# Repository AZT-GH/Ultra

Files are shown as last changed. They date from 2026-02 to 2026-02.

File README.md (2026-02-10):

# AZUltra

Copyright © 2026 Adam Zembrzuski

Licensed under the TAPR Open Hardware License (www.tapr.org/OHL)
A full copy of the TAPR Open Hardware License is available in license.txt

<hr>

AZUltra is a periodic buzzer designed for space-constrained environments. Applications include warning alerts or sleep prevention. It is primarily a testbed for CH32V005 integration in my future projects.



View the project entirely in your browser on KiCanvas - https://kicanvas.org/?repo=https%3A%2F%2Fgithub.com%2FAZT-GH%2FUltra%2Ftree%2Fmain%2FGH_UPLOAD%2FAZUltra

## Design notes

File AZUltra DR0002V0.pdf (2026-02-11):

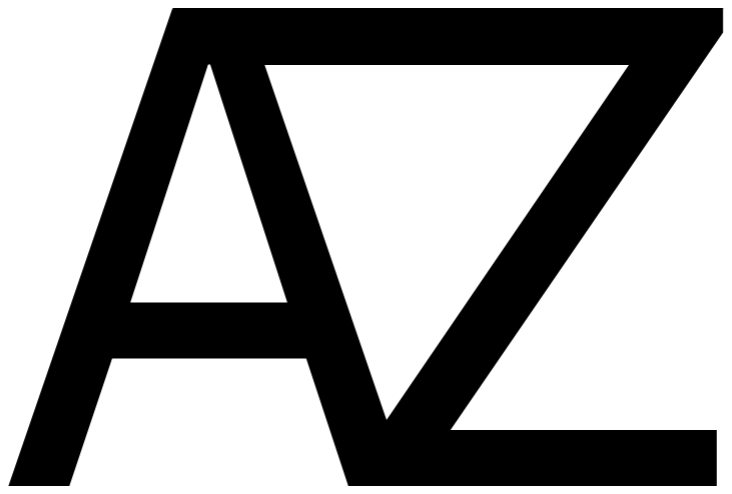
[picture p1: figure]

# AZUltra v0.01

## (Preliminary) Hardware Review 0002 - Version 1

AZUltra is a microcontroller-enabled buzzer with eight user-programmable modes.

### This document is intended as a review of the v0.01 hardware design. It will focus on the successes and failures of the first revision and detail a plan for future improvements if

another revision is deemed necessary. This is only a review of the hardware.

### Licensed under TAPR Open Hardware License

# CURRENTLY UNDER WRITING EXPECT CHANGES

# CONTENTS

CONTENTS | 1
CHANGELOG | 2
ABBREVIATIONS | 3
INTRODUCTION | 4
Context | 4
Design Intent | 4
Specification | 4
Schematic | 5
REVIEW | 6
Schematic | 6
Layout | 8
Improvements | 8
LICENSE | 9

# CHANGELOG

### V0 - Initial Commit - 10/02/26 - AZ V1 - Layout Review Complete - 11/02/26 - AZ

# ABBREVIATIONS

### uC - Microcontroller (GP) IO - (General Purpose) Input/Output PCB - Printed Circuit Board TVS - Transient Voltage Suppression EM - Electromagnetic ESD - Electrostatic Discharge PMOS - P Channel Metal Oxide Semiconductor Field Effect Transistor IC - Integrated Circuit

# INTRODUCTION

# Context

The idea for this project arose from the disappointment of a “cricket noise maker” I ordered

### from aliexpress. This product was comically quiet and when placed into the intended

environment - could be barely heard. Additionally, it used soldered batteries meaning it was difficult if not impossible to repair. It also was not user programmable due to a one time

### programmable microcontroller being used. This greatly inspired me to make my own

improved version.

# Design Intent

### To design a reliable, noticeable and repairable sound maker that would surpass options currently available on the market while maintaining a small form factor and low cost of

manufacture.

# Specification

## - At least 28 days of runtime on a single battery given one 200ms sound every

30 minutes.

## - Programming capability without expensive equipment

## - Versatile I/O allowing for connection to other equipment

## - Peak sound loudness of at least 80dB at 10cm

## - A maximum PCB size of 50mmx50mm

## - All small surface mount components on one side of the board (smaller than 15x15mm)

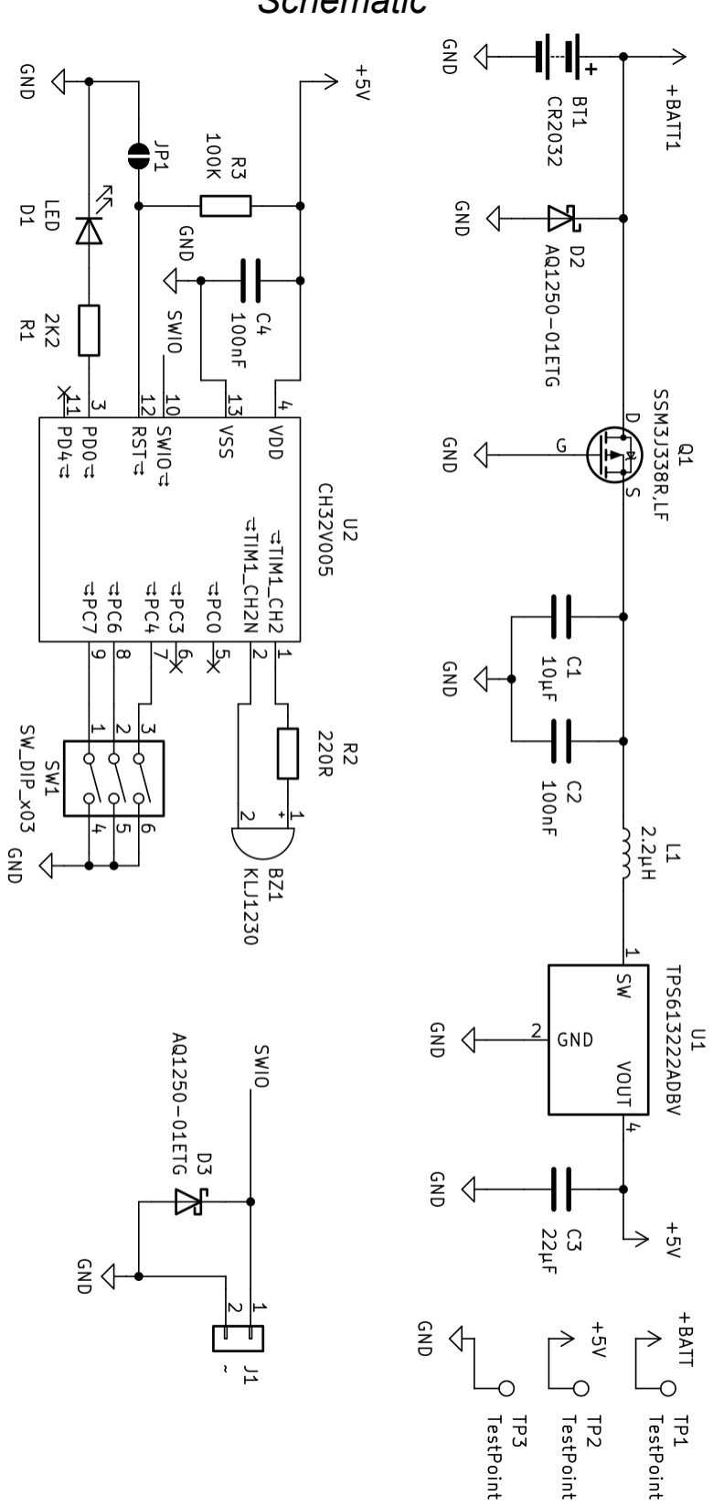
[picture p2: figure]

# Schematic

# REVIEW

# Schematic

The circuit (as seen in the previous page) is fairly simple. I chose the power source to be a

### CR2032 as they are fairly power dense, commonly available, do not require charging

circuitry and the holders come in a small footprint. An alternative would be the CR2450 as it has a much larger capacity, although they are more expensive, larger, and less common.

### The battery (and programming I/O) has a TVS diode to prevent damage from ESD events. I also implemented the Q1 PMOS for low loss reverse polarity protection. The specified part

should be substituted for a cheaper alternative if absolute cost-saving is a priority. I used the

### specified PMOS mostly due to the fact that I already had stock and that it had good

properties. Namely, low RDS_on and gate voltage.

This feeds into a boost converter boosting to 5V. The input caps are fairly standard and a low ESR power inductor with sufficient saturation current should be used for L1. In worst-case scenarios (low ambient temp and low quality, old cells) the converter would switch into PFM mode and leak noise through the uC timer peripheral into the piezo causing unwanted noise. For this reason a relatively large 22uf output cap was chosen in an attempt to mitigate the noise while keeping a relatively small package and cost. The boost converter was chosen as it had acceptable quiescent current and high efficiency . All with a very low bom count and

### implementation difficulty. A system voltage of 5V was chosen as it was near the maximum

acceptable operating voltage for the uC and enabled the piezo to stay at a consistent (and higher) loudness. There are also three test points to easily measure if the power is working.

Another reason for the development of this board was to test the CH32v00x platform of very cost efficient, feature-packed microcontrollers. The CH32v005 is one of the newer revisions and costs close to £0.25 per unit. They are available in a large range of packages, in this case I chose a very small QFN-12 unit. As for passives all it requires is a 100nF decoupling

### cap and a pull up on the reset pin. I chose a 100k pull up to balance noise immunity and power losses, I implemented the reset as an unlabelled jumper that can be bridged with a

screwdriver or similar. This is so that the device cannot be reset by third parties (without

### operating knowledge) in operation which is very useful for my use case. Ironically, this document removes that layer of security but if whoever finds this goes to the length of

reading this then they deserve to know how to reset the board.

### I dedicated one GPIO pin to an LED that can be used to verify programming and then can be

used by the user for whatever purposes they desire. I also used three GPIO pins for a 2 way

### dip switch to enable the user to switch between up to 8 modes on the fly. This could very

easily be switched out for a female connector to enable for the device to act on information

### from other devices (or expansion boards). As for connectors, the programming connector is a common JST-SH, Only two terminals are required due to the unique single wire

programming process (data and ground).

Finally, I chose a piezo buzzer due to their low current consumption and high loudness. The

### buzzer is connected push-pull to the complementary outputs of the advanced timer, timer1

on the ch32. This doubles the peak to peak potential difference compared to single end drive which greatly increases volume (~1.4x). I also added a series resistor to reduce ringing and noise (like aforementioned) while not drastically reducing volume.

# Layout

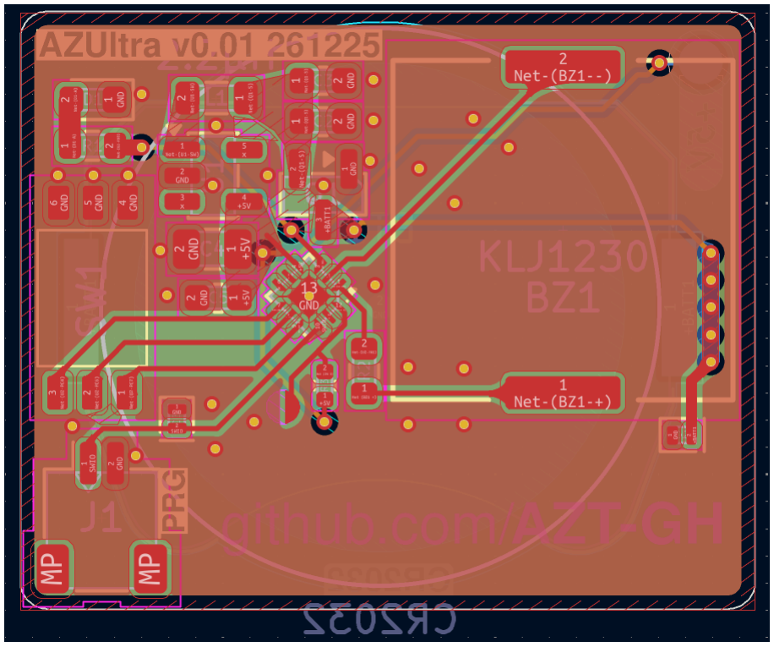
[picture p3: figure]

# Layout

I chose a four-layer PCB as it was the same cost from my supplier as a two-layer, and as I

### was concerned about the noise immunity of the PCB and thought that additional ground

planes would help. The stack is signal - ground - mixed - ground. The third layer consists of mostly a ground plane and some minimal power and signal routing.

### The PCB’s minimum size was constrained by the size of the CR2032 holder that I chose (Keystone 3034). I chose this holder as it was the easiest to solder by hand and also the smallest. A drawback was that the battery is not very securely secured and that there is

potential for soldermask on vias on the battery contact to be scraped, potentially causing shorts.

After defining the PCB edge, I roughly placed each component to ease routing later. Importantly, the passives that are a part of the DCDC switching loop are very close to the IC

### to reduce the loop area and EM emissions. They also all had ground vias placed near

ground pins to reduce the current loop and hence EM emissions. I also used copper fills for power connections to reduce their resistance thereby reducing power loss by ohmic losses.

The uC was placed centrally on the board to allow easy connection to all sides of the board.

### Similarly, the uC was rotated by 45 degrees to increase the ease of routing and enable larger separation between traces for noise immunity. Namely, the 3 dip switch needed 3 traces connected to the uC which were all spaced as much as possible to improve signal

integrity. Finally (as for functional considerations), I placed the programming connector near the edge of the PCB to allow for easy connections.

Considering aesthetical factors, I put an easily legible board label at the top, including name,

### version and date in knockout silkscreen. Similarly I labelled the programming header with

“PRG”. Also on the front side of the PCB, I removed the solder mask to expose my github on

### the ENIG/HASL. (github.com/AZT-GH) On the other side of the PCB I placed and labelled

the 5V test point and put silkscreen for the battery type on the battery entry.

# Improvements

### For some reason unknown to me I forgot to change the inner power traces to pours, in the next revision I would use pours to reduce the resistance as mentioned above. I would also

change the JST-SH connector for a more easily crimpable connector as after a lot of effort I was unable to crimp connectors and had to purchase precrimped wire.

In the next revision I would also replace the 3 position dip switch with a connector so that other boards could communicate to the AZUltra to enable environment based buzzing.

# LICENSE

### The TAPR Open Hardware License Version 1.0 (May 25, 2007) Copyright 2007 TAPR - http://www.tapr.org/OHL

PREAMBLE

Open Hardware is a thing - a physical artifact, either electrical or mechanical - whose design information is available to, and usable by, the public in a way that allows anyone to make, modify, distribute, and use that thing. In this preface, design information is called "documentation" and things created from it are called "products."

The TAPR Open Hardware License ("OHL") agreement provides a legal framework for Open Hardware projects. It may be used for any kind of product, be it a hammer or a computer motherboard, and is TAPR's contribution to the community; anyone may use the OHL for their Open Hardware project.

Like the GNU General Public License, the OHL is designed to guarantee your freedom to share and to create. It forbids anyone who receives rights under the OHL to deny any other licensee those same rights to copy, modify, and distribute documentation, and to make, use and distribute products based on that documentation.

Unlike the GPL, the OHL is not primarily a copyright license. While copyright protects documentation from unauthorized copying, modification, and distribution, it has little to do with your right to make, distribute,
or use a product based on that documentation. For better or worse, patents play a significant role in those activities. Although it does not prohibit
anyone from patenting inventions embodied in an Open Hardware design, and of course cannot prevent a third party from enforcing their patent rights,
those who benefit from an OHL design may not bring lawsuits claiming that design infringes their patents or other intellectual property.

The OHL addresses unique issues involved in the creation of tangible, physical things, but does not cover software, firmware, or code loaded into programmable devices. A copyright-oriented license such as the GPL better suits these creations.

How can you use the OHL, or a design based upon it? While the terms and conditions below take precedence over this preamble, here is a summary:

* You may modify the documentation and make products based upon it.

* You may use products for any legal purpose without limitation.

* You may distribute unmodified documentation, but you must include the complete package as you received it.

* You may distribute products you make to third parties, if you either include the documentation on which the product is based, or make it available without charge for at least three years to anyone who requests it.

* You may distribute modified documentation or products based on it, if you:
* License your modifications under the OHL.
* Include those modifications, following the requirements stated below.
* Attempt to send the modified documentation by email to any of the developers who have provided their email address. This is a good faith obligation - if the email fails, you need do nothing more
and may go on with your distribution.

* If you create a design that you want to license under the OHL, you should:
* Include this document in a file named LICENSE (with the appropriate extension) that is included in the documentation package.
* If the file format allows, include a notice like "Licensed under
the TAPR Open Hardware License (www.tapr.org/OHL)" in each documentation file. While not required, you should also include this notice on printed circuit board artwork and the product itself; if space is limited the notice can be shortened or abbreviated.
* Include a copyright notice in each file and on printed circuit board artwork.
* If you wish to be notified of modifications that others may make, include your email address in a file named "CONTRIB.TXT" or something similar.

* Any time the OHL requires you to make documentation available to others, you must include all the materials you received from the upstream licensors. In addition, if you have modified the documentation:
* You must identify the modifications in a text file (preferably
named "CHANGES.TXT") that you include with the documentation. That file must also include a statement like "These modifications are licensed under the TAPR Open Hardware License."
* You must include any new files you created, including any manufacturing files (such as Gerber files) you create in the course of making products.
* You must include both "before" and "after" versions of all files you modified.
* You may include files in proprietary formats, but you must also include open format versions (such as Gerber, ASCII, Postscript, or PDF) if your tools can create them.

TERMS AND CONDITIONS

1. Introduction
1.1 This Agreement governs how you may use, copy, modify, and distribute Documentation, and how you may make, have made, and distribute Products based on that Documentation. As used in this Agreement, to "distribute" Documentation means to directly or indirectly make copies available to a third party, and to "distribute" Products means to directly or indirectly give, loan, sell or otherwise transfer
them to a third party.

1.2 "Documentation" includes:
(a) schematic diagrams;

(b) circuit or circuit board layouts, including Gerber and other
data files used for manufacture;
(c) mechanical drawings, including CAD, CAM, and other data files used for manufacture;
(d) flow charts and descriptive text; and
(e) other explanatory material.
Documentation may be in any tangible or intangible form of expression, including but not limited to computer files in open or proprietary formats and representations on paper, film, or other media.

1.3 "Products" include:
(a) circuit boards, mechanical assemblies, and other physical parts and components;
(b) assembled or partially assembled units (including components and subassemblies); and
(c) parts and components combined into kits intended for assembly by others;
which are based in whole or in part on the Documentation.

1.4 This Agreement applies to any Documentation which contains a notice stating it is subject to the TAPR Open Hardware License, and to all Products based in whole or in part on that Documentation. If Documentation is distributed in an archive (such as a "zip" file) which includes this document, all files in that archive are subject to this Agreement unless they are specifically excluded. Each person who contributes content to the Documentation is referred to in this Agreement as a "Licensor."

1.5 By (a) using, copying, modifying, or distributing the
Documentation, or (b) making or having Products made or distributing them, you accept this Agreement, agree to comply with its terms, and become a "Licensee." Any activity inconsistent with this Agreement will automatically terminate your rights under it (including the immunities from suit granted in Section 2), but the rights of others who have received Documentation, or have obtained Products, directly or indirectly from you will not be affected so long as they fully comply
with it themselves.

1.6 This Agreement does not apply to software, firmware, or code loaded into programmable devices which may be used in conjunction with Documentation or Products. Such software is subject to the license terms established by its copyright holder(s).

2. Patents
2.1 Each Licensor grants you, every other Licensee, and every possessor or user of Products a perpetual, worldwide, and royalty-free immunity from suit under any patent, patent application, or other intellectual property right which he or she controls, to the extent necessary to make, have made, possess, use, and distribute Products. This immunity does not extend to infringement arising from modifications subsequently made by others.

2.2 If you make or have Products made, or distribute Documentation that you have modified, you grant every Licensor, every other Licensee, and every possessor or user of Products a perpetual, worldwide, and royalty-free immunity from suit under any patent, patent application, or other intellectual property right which you control, to the extent necessary to make, have made, possess, use, and distribute Products.

This immunity does not extend to infringement arising from modifications subsequently made by others.

2.3 To avoid doubt, providing Documentation to a third party for the sole purpose of having that party make Products on your behalf is not considered "distribution,"\" and a third party's act of making Products solely on your behalf does not cause that party to grant the immunity described in the preceding paragraph.

2.4 These grants of immunity are a material part of this Agreement, and form a portion of the consideration given by each party to the other. If any court judgment or legal agreement prevents you from granting the immunity required by this Section, your rights under this Agreement will terminate and you may no longer use, copy, modify or distribute the Documentation, or make, have made, or distribute Products.

3. Modifications
You may modify the Documentation, and those modifications will become part of the Documentation. They are subject to this Agreement, as are Products based in whole or in part on them. If you distribute the modified Documentation, or Products based in whole or in part upon it, you must email the modified Documentation in a form compliant with Section 4 to each Licensor who has provided an email address with the Documentation. Attempting to send the email completes your obligations under this Section and you need take no further action if any address fails.
4. Distributing Documentation
4.1 You may distribute unmodified copies of the Documentation in its entirety in any medium, provided that you retain all copyright and other notices (including references to this Agreement) included by each

Licensor, and include an unaltered copy of this Agreement.
4.2 You may distribute modified copies of the Documentation if you comply with all the requirements of the preceding paragraph and:
(a) include a prominent notice in an ASCII or other open format file identifying those elements of the Documentation that you changed, and stating that the modifications are licensed under the terms of this Agreement;
(b) include all new documentation files that you create, as well as both the original and modified versions of each file you change (files may be in your development tool's native file format,
but if reasonably possible, you must also include open format, such as Gerber, ASCII, Postscript, or PDF, versions);
(c) do not change the terms of this Agreement with respect to subsequent licensees; and
(d) if you make or have Products made, include in the Documentation all elements reasonably required to permit others to make Products, including Gerber, CAD/CAM and other files used for manufacture.
5. Making Products
5.1 You may use the Documentation to make or have Products made, provided that each Product retains any notices included by the Licensor (including, but not limited to, copyright notices on circuit boards).

5.2 You may distribute Products you make or have made, provided that you include with each unit a copy of the Documentation in a form consistent with Section 4. Alternatively, you may include either (i) an offer valid for at least three years to provide that Documentation, at
no charge other than the reasonable cost of media and postage, to any person who requests it; or (ii) a URL where that Documentation may be downloaded, available for at least three years after you last distribute the Product.
6. NEW LICENSE VERSIONS
TAPR may publish updated versions of the OHL which retain the same general provisions as the present version, but differ in detail to
address new problems or concerns, and carry a distinguishing version number. If the Documentation specifies a version number which applies to it and "any later version", you may choose either that version or any later version published by TAPR. If the Documentation does not specify a version number, you may choose any version ever published by TAPR. TAPR owns the copyright to the OHL, but grants permission to any person to copy, distribute, and use it in unmodified form.
7. WARRANTY AND LIABILITY LIMITATIONS
7.1 THE DOCUMENTATION IS PROVIDED ON AN"AS-IS" BASIS WITHOUT WARRANTY OF ANY KIND, TO THE EXTENT PERMITTED BY APPLICABLE LAW. ALL WARRANTIES, EXPRESS OR IMPLIED, INCLUDING BUT NOT LIMITED TO ANY WARRANTIES OF MERCHANTABILITY, FITNESS FOR A PARTICULAR PURPOSE, AND TITLE, ARE HEREBY EXPRESSLY DISCLAIMED.

7.2 IN NO EVENT UNLESS REQUIRED BY APPLICABLE LAW WILL ANY LICENSOR
BE LIABLE TO YOU OR ANY THIRD PARTY FOR ANY DIRECT, INDIRECT,
INCIDENTAL, CONSEQUENTIAL, PUNITIVE, OR EXEMPLARY DAMAGES ARISING OUT OF THE USE OF, OR INABILITY TO USE, THE DOCUMENTATION OR PRODUCTS, INCLUDING BUT NOT LIMITED TO CLAIMS OF INTELLECTUAL PROPERTY INFRINGEMENT OR LOSS OF DATA, EVEN IF THAT PARTY HAS BEEN ADVISED OF THE POSSIBILITY OF SUCH DAMAGES.

7.3 You agree that the foregoing limitations are reasonable due to
the non-financial nature of the transaction represented by this
Agreement, and acknowledge that were it not for these limitations, the Licensor(s) would not be willing to make the Documentation available to you.

7.4 You agree to defend, indemnify, and hold each Licensor harmless from any claim brought by a third party alleging any defect in the design, manufacture, or operation of any Product which you make, have made, or distribute pursuant to this Agreement.

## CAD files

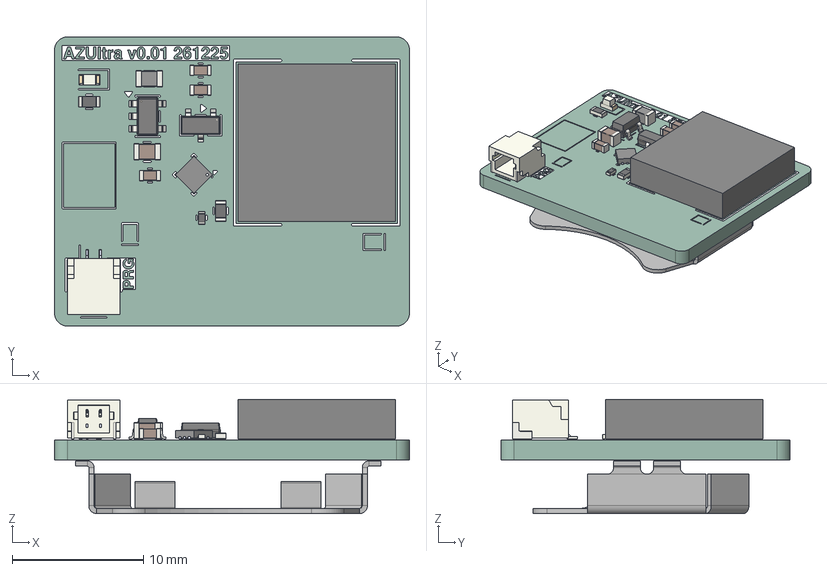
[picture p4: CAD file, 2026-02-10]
GH_UPLOAD/AZUltra/AZUltra.step
27.0 x 22.0 x 8.68 mm
R_0402_1005Metric
LED_0603_1608Metric
L_0805_2012Metric
SOT-23
KLJ1230
SOT-23-5
C_0603_1608Metric x 3
C_0805_2012Metric
Body_Solid1
Body001_Solid1
Array_Solid1 x 3
Array001_Solid2 x 2
Body002_Solid1
Array002_Solid1 x 3
Array003_Solid2 x 2
Body003_Solid1
Body004_Solid1
JST_SH_SM02B-SRSS-TB_1x02-1MP_P1.00mm_Horizontal
SM02B-SRSS-TB-LF
R_0603_1608Metric x 2
BatteryHolder_Keystone_3034_1x20mm
AZUltra_silkscreen x 2
AZUltra_PCB

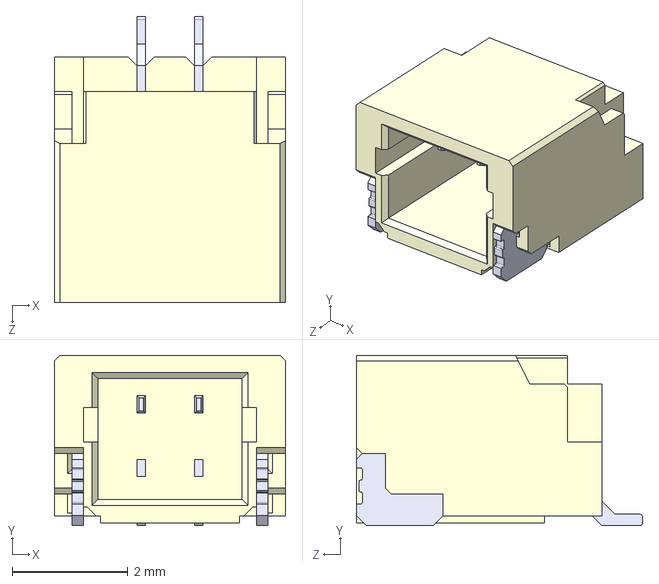
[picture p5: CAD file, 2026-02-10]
GH_UPLOAD/step/SM02B-SRSS-TB-LF.STEP
4.00 x 2.95 x 4.95 mm

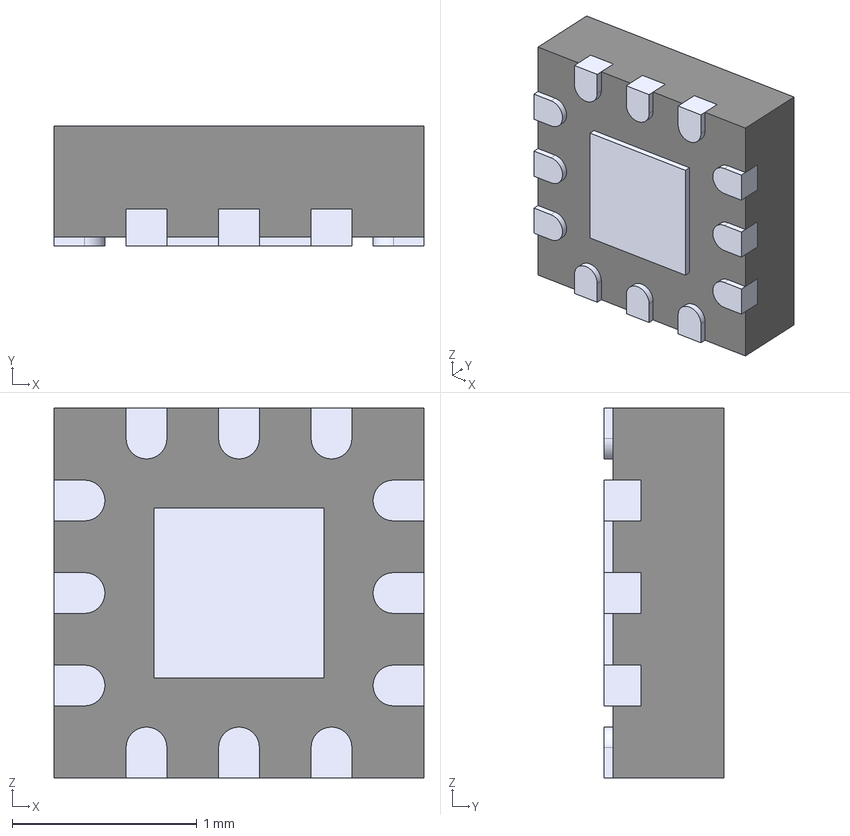
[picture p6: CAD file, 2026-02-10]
GH_UPLOAD/step/SKYA21003.STEP
2.00 x 0.65 x 2.00 mm
Body_Solid1
Body001_Solid1
Array_Solid1 x 3
Array001_Solid2 x 2
Body002_Solid1
Array002_Solid1 x 3
Array003_Solid2 x 2
Body003_Solid1
Body004_Solid1

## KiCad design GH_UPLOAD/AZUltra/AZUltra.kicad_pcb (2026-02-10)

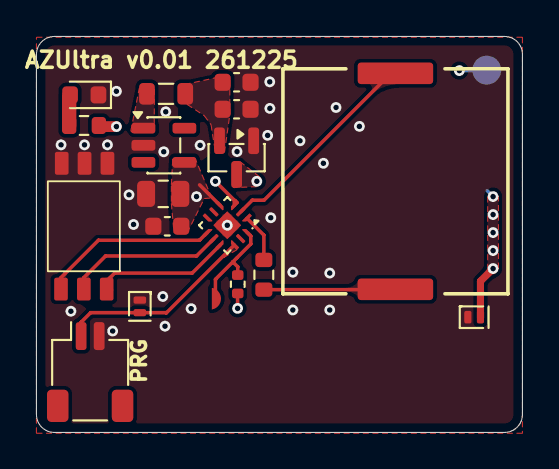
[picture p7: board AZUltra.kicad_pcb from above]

Board: 4 copper layers, 27.0 x 22.0 mm, 18 parts (1 on the bottom side), 15 nets.

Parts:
BT1: CR2032; BatteryHolder_Keystone_3034_1x20mm
BZ1: KLJ1230
C2: 4.7μF; C_0603_1608Metric
C3, C5: 100nF; C_0603_1608Metric
C4: 22μF; C_0805_2012Metric
D1: LED; LED_0603_1608Metric
D2, D3: AQ1250-01ETG; D_SOD-882_DFN1006-2_TVS
J1: JST_SH_SM02B-SRSS-TB_1x02-1MP_P1.00mm_Horizontal
L1: 2.2μH; L_0805_2012Metric
Q1: SSM3J338R,LF; SOT-23
R1: 2K2; R_0603_1608Metric
R2: 220R; R_0603_1608Metric
R3: 100K; R_0402_1005Metric
SW1: SW_DIP_x03; SMXMS-03K-TR
U1: TPS613222ADBV; SOT-23-5
U2: CH32V005; IDT_QFN-12-1EP_2x2mm_P0.5mm_EP1.1x1.1mm

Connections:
+5V: C4.1, C5.1, R3.1, U1.4 (VOUT), U2.4 (VDD)
+BATT1: BT1.1 (+), D2.2 (K), Q1.3 (D)
/SWIO: D3.2 (K), J1.1, U2.10 (SWIO)
GND: BT1.2 (-), C2.2, C3.2, C4.2, C5.2, D1.1 (K), D2.1 (A), D3.1 (A), J1.2, Q1.1 (G), SW1.4, SW1.5, SW1.6, U1.2 (GND), U2.13 (VSS)
unnamed: BZ1.1 (+), R2.1
unnamed: BZ1.2 (-), U2.2 (TIM1_CH2N)
unnamed: D1.2 (A), R1.1
unnamed: R3.2, U2.12 (RST)
unnamed: C2.1, C3.1, L1.1, Q1.2 (S)
unnamed: L1.2, U1.1 (SW)
unnamed: R2.2, U2.1 (TIM1_CH2)
unnamed: SW1.3, U2.7 (PC4)
unnamed: SW1.2, U2.8 (PC6)
unnamed: SW1.1, U2.9 (PC7)
unnamed: R1.2, U2.3 (PD0)

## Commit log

2026-02-10 Project Bulk Upload
    [AZUltra-B_Cu.gbr, AZUltra-B_Mask.gbr, AZUltra-B_Paste.gbr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]
2026-02-10 Update schematic
    [AZUltra.kicad_sch]
2026-02-10 Update Schematic
    Actually new schematic uploaded this time
    [AZUltra.kicad_sch]
2026-02-10 Schematic reuplaod
